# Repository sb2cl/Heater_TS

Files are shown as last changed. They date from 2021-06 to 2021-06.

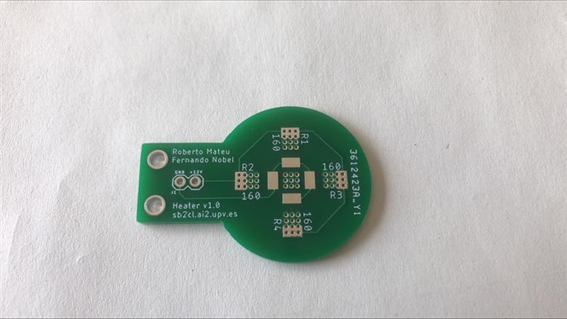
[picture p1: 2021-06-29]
pcb/PlacaAbajo.png

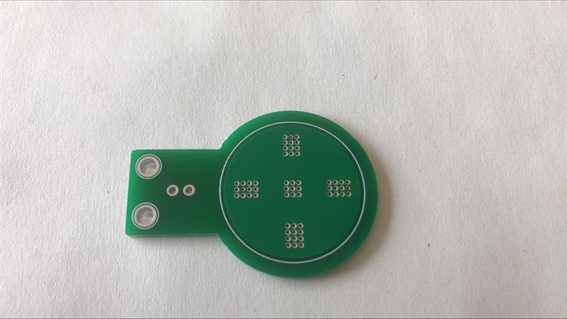
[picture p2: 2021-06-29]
pcb/PlacaArriba.png

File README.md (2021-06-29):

# Control de temperatura de un mini-biorreactor mediante un sensor de infrarrojos

Este repositorio recopila el código generado por Roberto Mateu en el desarrollo de su TFG.

## Matlab

La carpeta "1_IdentificacionModelo" contiene el código necesario para obtener modelos a partir de los datos experimentales de un bucle abierto mediante la herramienta SystemIdent. Además se incluye un ejemplo: datos reales e imágenes del modelo obtenido.

La carpeta "2_ValidacionModelo" contiene el código necesario para implementar el modelo obtenido en un simulador y comprobar si coincide con los datos experimentales.

Por último, la carpeta "3_SimuladorSimulink", contiene un simulador de un bucle de control en lazo cerrado con control de referencia.

## PCB

En la carpeta "pcb" se incluyen todos los archivos de Eagle usados para desarrollar/implementar la pcb del calentador basado en resistencias planas. También se incluyen imágenes con los resultados.

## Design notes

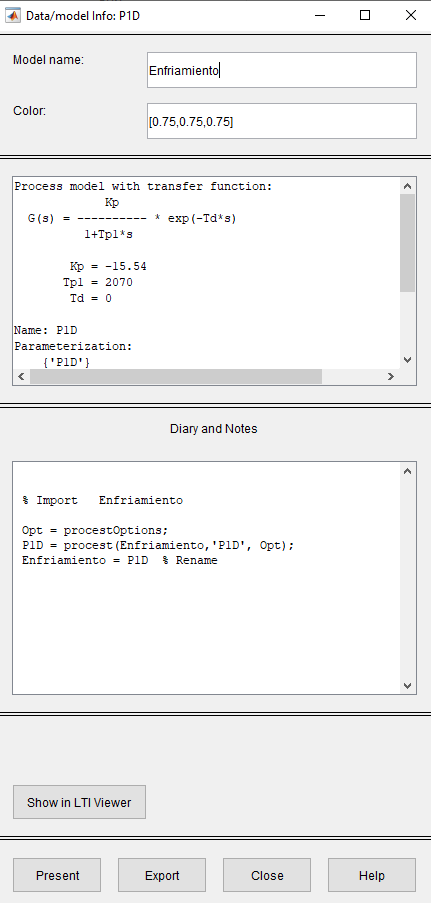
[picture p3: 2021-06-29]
matlab/1_IdentificacionModelo/ModeloEnfriamiento.PNG

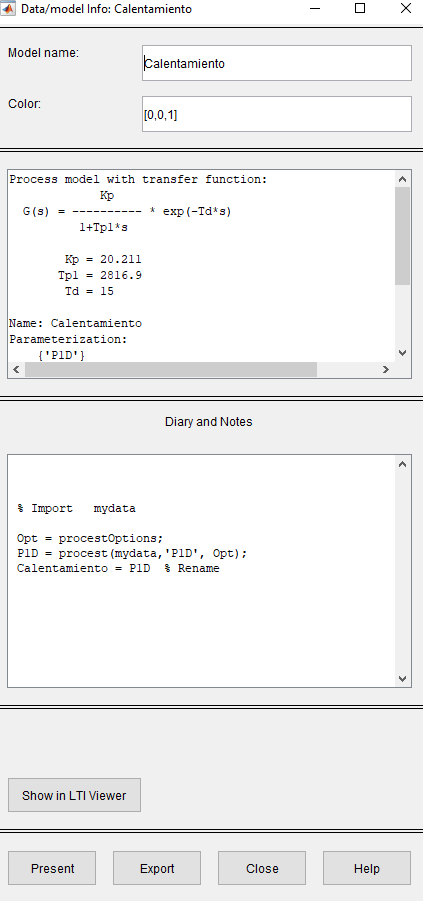
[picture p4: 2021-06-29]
matlab/1_IdentificacionModelo/ModeloCalentamiento.PNG

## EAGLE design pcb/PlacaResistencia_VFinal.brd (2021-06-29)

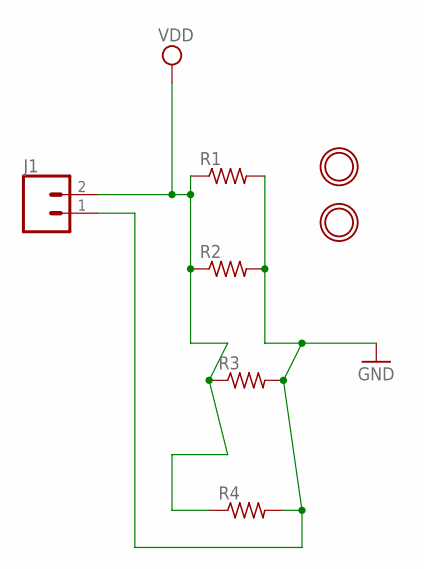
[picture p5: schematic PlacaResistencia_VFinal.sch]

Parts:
GND, GND2: MOUNTINGHOLE2.5; MOUNTINGHOLE_2.5_PLATED
J1: CONN_02; 1X02
R1, R2, R3, R4: R-US_R2512; R2512

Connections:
GND: J1.1, R1.2, R2.2, R3.2, R4.2
VDD: J1.2, R1.1, R2.1, R3.1, R4.1

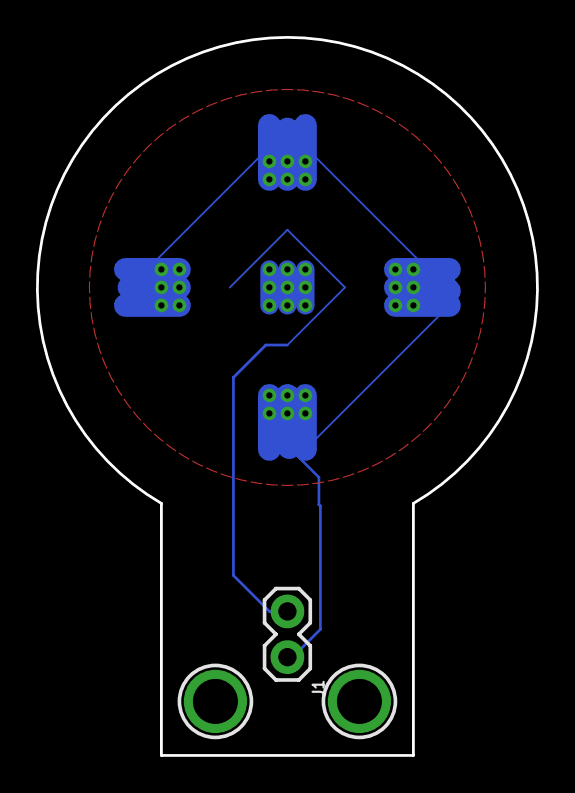
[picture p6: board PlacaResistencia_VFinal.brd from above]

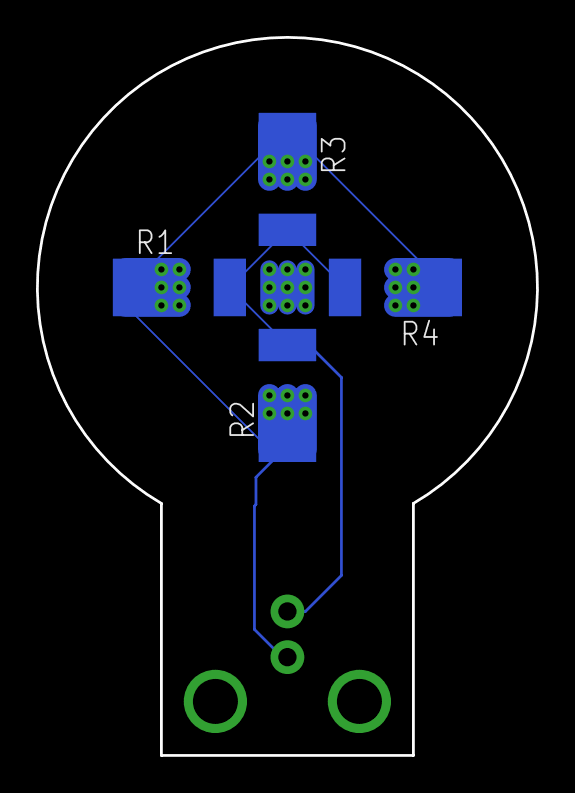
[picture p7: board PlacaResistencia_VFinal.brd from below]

Board: 2 copper layers, 27.8 x 39.9 mm, 7 parts (4 on the bottom side), 2 nets.

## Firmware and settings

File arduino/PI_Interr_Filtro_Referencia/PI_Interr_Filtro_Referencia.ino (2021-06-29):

//Librerias a incluir: Wire.h para comunicación I2C, Adafruit_MLX90614.h para sensor Temperatura y LiquidCrystal.h para pantalla
#include <Wire.h>
#include <Adafruit_MLX90614.h>
#include <LiquidCrystal.h>
#include <TimerOne.h>

//Definición del Objeto STemp como sensor de Temperatura
Adafruit_MLX90614 STemp = Adafruit_MLX90614();

//Definición del Objeto lcd como pantalla conectado a pines 7,6,5,4,3,2
LiquidCrystal lcd(7,6,5,4,3,2);

//Declaración de variables
volatile float tamb,tobj,kp,ti,ts,set,ref,e,e1=0,p0,p1,u,u1,tobj1,dT=0,alpha,beta;
volatile int gate=8,salida,a;
int b1=9,b2=10,b3=11,b4=12,demora; //Pines del stepper
volatile bool b=1; //imprimir por pantalla cada cierto tiempo

//Inicialización del Serial Monitor y del sensor, establecer gate Output, inicializar pantalla como 16 caract y 2 lineas
void setup() {
  Serial.begin(9600);
  STemp.begin();
  pinMode(gate,OUTPUT);
  lcd.begin(16, 2);
  //Valores PID
  kp=3.96*0.5;
  ti=22*10; //De 30 a 42 sin overshoot
  ts=0.5*1000;
  p0=kp;
  p1=kp*((ts-ti)/ts);
  //Valor deseado de temperatura
  set=30;
  //Valor filtro Temperatura
  alpha=0.75;

  tobj=STemp.readObjectTempC();
  tobj1=tobj;
  
  //Inicializar pines del stepper y velocidad (demora entre pasos)
  pinMode(b1, OUTPUT);
  pinMode(b2, OUTPUT);
  pinMode(b3, OUTPUT);
  pinMode(b4, OUTPUT);
  demora = 2;
  
  //Inicializar interrupts
  Timer1.initialize(500000); //Interrupt cada ciertos micro segundos
  Timer1.attachInterrupt(controlPI); //Llamar a la función cuando salte interrupt con preferencia
}

void loop() {
  //Plot en pantalla: Colocar cursor e imprimir valores
  if(b==1){
      lcd.setCursor(0,0);
      lcd.print("T Res C = ");
      lcd.print(tobj);
      lcd.setCursor(0,1);
      lcd.print("T Set C = ");
      lcd.print(set);
      Serial.print(millis());
      Serial.print(",");
      Serial.print(salida);
      Serial.print(",");
      Serial.print(tobj);
      Serial.print(",");
      Serial.print(dT*1000);
      Serial.print(",");
      Serial.println(ref);
      //Lectura de Temperatura
      tobj=STemp.readObjectTempC();
      b=0;

  }

  
  

  //Control del motor stepper remover
  remover();


}

void controlPI(){
  //Tiempo de reloj entre interrupts de 100ms para tomar 5 valores
  //y hacer la media entre ellos, de manera que tomo un valor promediado cada 500ms


  //PI
  //Filtro temperatura
  tobj=tobj*(1-alpha)+alpha*tobj1;
  //Calculo derivada
  dT=(tobj-tobj1)/0.5;
  //Control de Referencia
  beta=set-tobj-dT*60;
  if(beta<0){
    ref=0;
  }
  else{
    ref=set;
  }
  //Calculo del error
  e=ref-tobj;
  u=p0*e+p1*e1+u1;
  
  //Anti-Wind up + control de temperatura max (2V max para no alcanzar 50 grados)
  if(u>12){
    u=12;
  }
  if(u<0){
    u=0;
  }
  //Accion de control
  salida=(255.0/12.0)*u;
  analogWrite(gate,salida);
  //Almacen de variables
  e1=e;
  u1=u;
  tobj1=tobj;
  //Limpiar variable
  b=1;
}

void remover(){
  digitalWrite(b1, HIGH);  // paso 1 
  digitalWrite(b2, LOW);
  digitalWrite(b3, LOW);
  digitalWrite(b4, LOW);
  delay(demora);

  digitalWrite(b1, HIGH);  
  digitalWrite(b2, HIGH);
  digitalWrite(b3, LOW);
  digitalWrite(b4, LOW);
  delay(demora);

  digitalWrite(b1, LOW); // paso 2
  digitalWrite(b2, HIGH);
  digitalWrite(b3, LOW);
  digitalWrite(b4, LOW);
  delay(demora);

  digitalWrite(b1, LOW);
  digitalWrite(b2, HIGH);
  digitalWrite(b3, HIGH);
  digitalWrite(b4, LOW);
  delay(demora);

  digitalWrite(b1, LOW); // paso 3
  digitalWrite(b2, LOW);
  digitalWrite(b3, HIGH);
  digitalWrite(b4, LOW);
  delay(demora);

  digitalWrite(b1, LOW); 
  digitalWrite(b2, LOW);
  digitalWrite(b3, HIGH);
  digitalWrite(b4, HIGH);
  delay(demora);

  digitalWrite(b1, LOW); // paso 4
  digitalWrite(b2, LOW);
  digitalWrite(b3, LOW);
  digitalWrite(b4, HIGH);
  delay(demora);

  digitalWrite(b1, HIGH);
  digitalWrite(b2, LOW);
  digitalWrite(b3, LOW);
  digitalWrite(b4, HIGH);
  delay(demora);
}

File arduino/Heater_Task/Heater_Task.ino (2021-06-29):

#include "Debugger.h"
#include "Task.h"
#include "TaskScheduler.h"

#include "BlinkTask.h"
#include "StirrerTask.h"
#include "ControllerTask.h"

TaskScheduler *scheduler;

Debugger *debugger;
Task *tasks[4];

// the setup function runs once when you press reset or power the board
void setup() {
  Serial.begin(9600);

  debugger = new Debugger();

  tasks[0] = new BlinkTask(0,1000,NULL);
  tasks[1] = new StirrerTask(0,100,NULL);
  tasks[2] = new ControllerTask(0,100,debugger);
  tasks[3] = debugger;
  scheduler = new TaskScheduler(tasks, NUM_TASKS(tasks));
}

// the loop function runs over and over again forever
void loop() {
  scheduler->run(millis()); 
}

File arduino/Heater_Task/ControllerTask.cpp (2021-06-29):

#include "ControllerTask.h"

/**
   @brief: Constructor of StirrerTask.

   @param: uint64_t _now           Time in 100ns of first execution of the task.
         : uint64_t _rate          Time interval in 100ns of execution of the task.
         : Debugger *_ptrDebugger  Pointer to debugger.

*/
ControllerTask::ControllerTask(uint64_t _now, uint64_t _rate, Debugger *_ptrDebugger)
  : TimedTask(_now),
    rate(_rate),
    ptrDebugger(_ptrDebugger)
{
  T = T_ini;
  t = 0;

  u1 = 0;
  error1 = 0;
}

/**
   @brief: Destructor of ControllerTask.

*/
ControllerTask::~ControllerTask() {}

/**
   @brief: Simulate an time step.

   @param: void.

   @return: void
*/
void ControllerTask::simulate() {
  dT = a * u + b * (T_amb - T);
  T = T + dT * h;
  t = t + h;
}

/**
   @brief: Execute the controller.

   @param: void

   @return: void
*/
void ControllerTask::controller() {
  float error = T_ref - T;
  u = error * K_p + K_i * error1 + u1;

  if (u > 255) {
    u = 255;
  }
  if (u < 0) {
    u = 0;
  }

  u1 = u;
  error1 = error;
}

/**
   @brief: Do a step in the stirrer.

   @param: uint64_t now Current time in 100 nanoseconds.

   @return: void
*/
void ControllerTask::run(uint64_t now) {

  controller();
  simulate();

  if (ptrDebugger) {
    Serial.print("Ref=");
    Serial.print(dT);
    Serial.print("ºC T=");
    Serial.print(T);
    Serial.print("ºC");
    Serial.print(" u=");
    Serial.print(u);
    Serial.print(" time=");
    Serial.print(t);
    Serial.print(" min");
    Serial.println();
  }

  // Run again in the specified time.
  incRunTime(rate);
}

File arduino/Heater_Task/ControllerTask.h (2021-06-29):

#ifndef CONTROLLERTASK_H
#define CONTROLLERTASK_H

#include <inttypes.h>

#include "Task.h"
#include "Debugger.h"

/**
   @brief This class implements the temperature controller.


*/
class ControllerTask: public TimedTask {
  public:
    ControllerTask(uint64_t now, uint64_t rate, Debugger *_ptrDebugger = NULL);
    ~ControllerTask();

    // Simulator variables.
    float a = 0.00549;  // Heating constant.
    float b = 0.03;     // Cooling constant.
    float h = 0.1;      // Integration time.
    float T_ini = 25;   // Initial temperature.
    float T_amb = 25;   // Ambient temperature.
    float T;            // Actual temperature.
    float dT;           // Derivative temperature.
    float t;            // Actual time in simulation.

    // Controller variables.
    float K_p = 10;      // Proportional gain.
    float K_i = 0.1;      // Integral gain.
    float T_ref = 30;   // Reference temperature.
    float u1;           // Last control action.
    float u;            // Actual control action.
    float error1;       // Last error.

    // Reference controller.
    float alpha;

  private:
    uint64_t rate; // Delay between steps.
    Debugger *ptrDebugger;

    void simulate();
    void controller();
    void run(uint64_t now) override;

};

#endif /* end of include guard: ControllerTask */

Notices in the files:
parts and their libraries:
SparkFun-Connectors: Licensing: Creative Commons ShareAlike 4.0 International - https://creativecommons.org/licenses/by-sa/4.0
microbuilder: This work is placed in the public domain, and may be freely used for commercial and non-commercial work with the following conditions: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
